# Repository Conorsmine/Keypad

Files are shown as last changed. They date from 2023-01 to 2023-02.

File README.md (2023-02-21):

# Keypad
Current progress on the project:


## Resources
ai03 Guide:       https://wiki.ai03.com/books/pcb-design/page/pcb-guide-part-5---creating-the-pcb  
Masterzen Guide:  https://www.masterzen.fr/2020/10/20/designing-a-keyboard-part3/

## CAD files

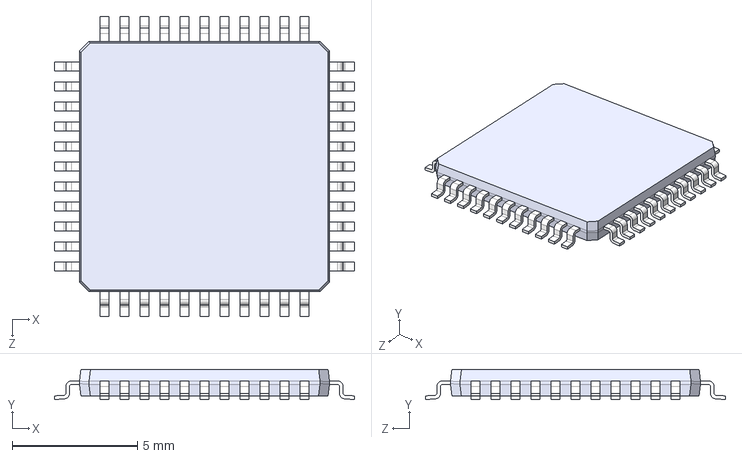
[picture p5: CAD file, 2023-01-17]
keypad/ATMEGA32U4-AU/ATMEGA32U4-AU.step
12.0 x 1.20 x 12.0 mm

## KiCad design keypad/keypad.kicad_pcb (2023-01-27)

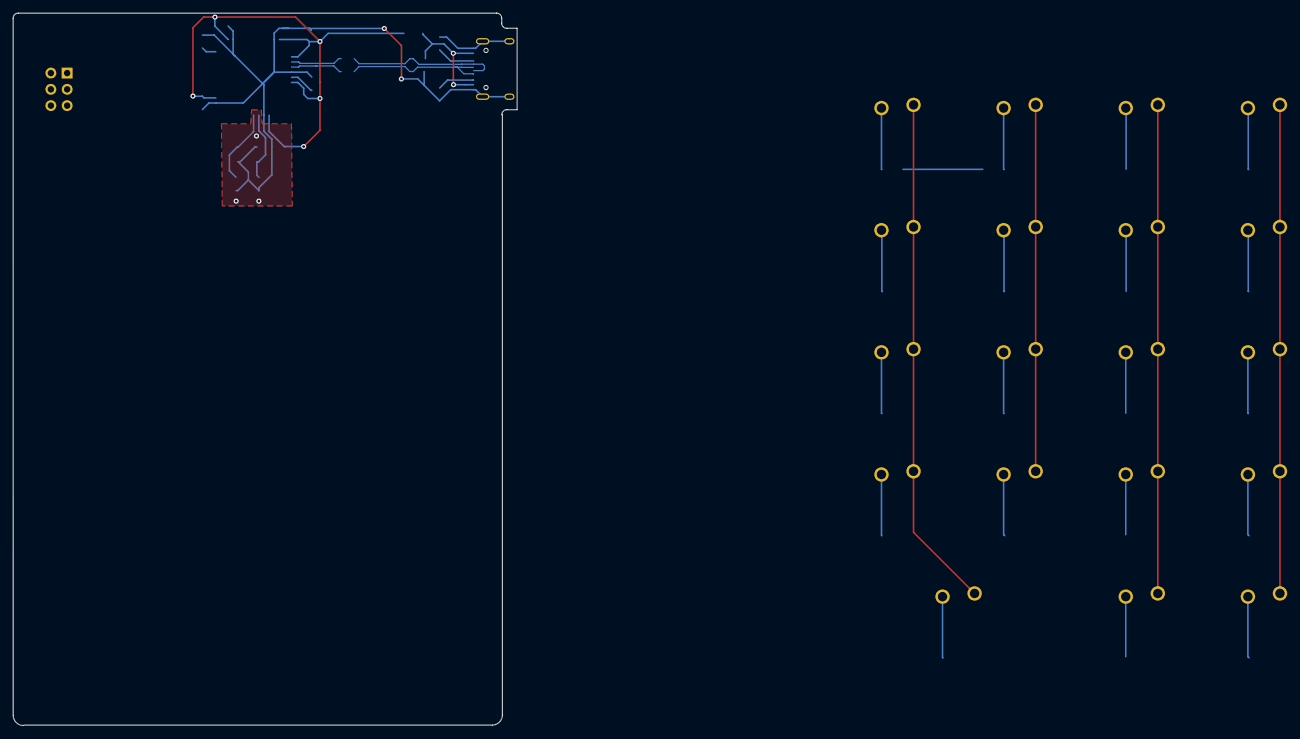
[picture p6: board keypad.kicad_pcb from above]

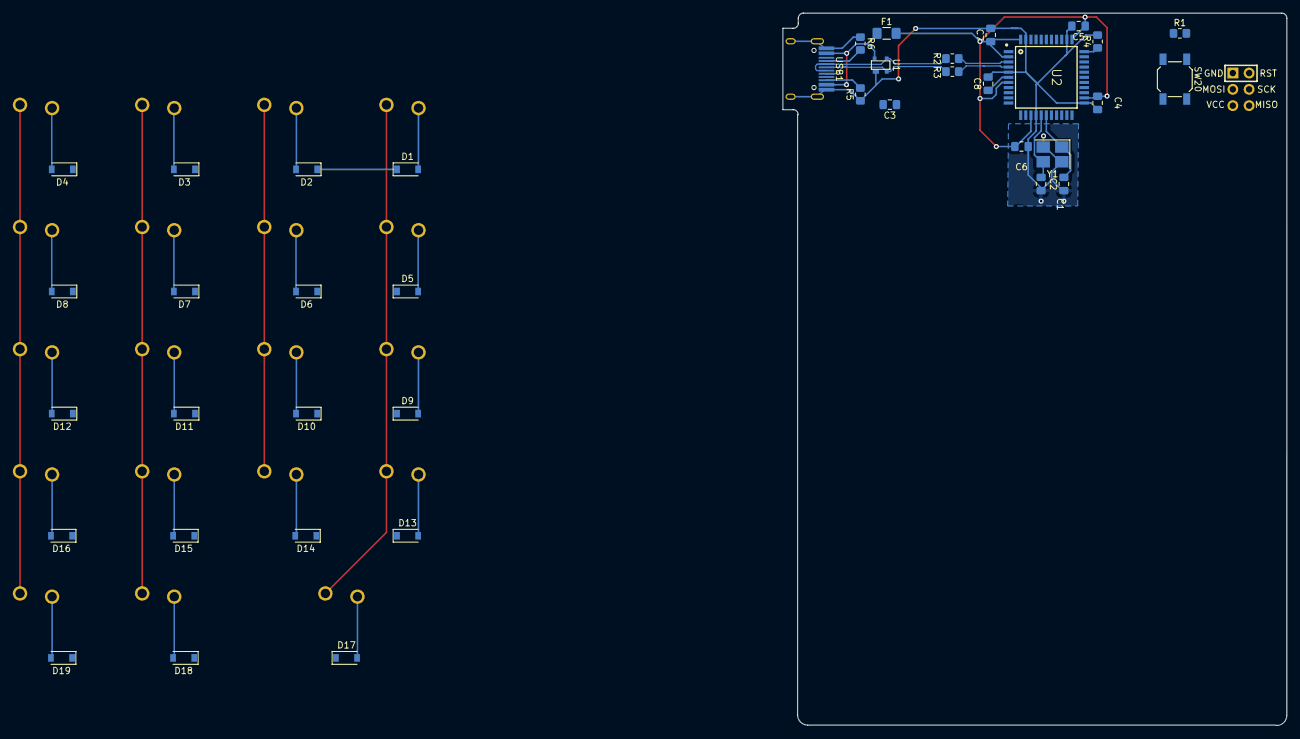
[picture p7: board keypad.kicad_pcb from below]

Board: 2 copper layers, 78.6 x 111.1 mm, 59 parts (40 on the bottom side), 45 nets.

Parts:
C1, C2: 22p; C_0805_2012Metric_Pad1.18x1.45mm_HandSolder
C3, C4, C5, C6: 0.1u; C_0805_2012Metric_Pad1.18x1.45mm_HandSolder
C7: 10u; C_0805_2012Metric_Pad1.18x1.45mm_HandSolder
C8: 1u; C_0805_2012Metric_Pad1.18x1.45mm_HandSolder
D1, D2, D3, D4, D5, D6, D7, D8, D9, D10, D11, D12, D13, D14, D15, D16, D17, D18, D19: D; D_SOD-123
F1: 500mA; Fuse_1206_3216Metric_Pad1.42x1.75mm_HandSolder
J1: AVR-ISP-6; Reset_Pretty-Mask
R1, R4: 10k; R_0805_2012Metric_Pad1.20x1.40mm_HandSolder
R2, R3: 22; R_0805_2012Metric_Pad1.20x1.40mm_HandSolder
R5, R6: 5.1k; R_0805_2012Metric_Pad1.20x1.40mm_HandSolder
SW1: num; ALPS-1U
SW2: div; ALPS-1U
SW3: mult; ALPS-1U
SW4: min; ALPS-1U
SW5: #7; ALPS-1U
SW6: #8; ALPS-1U
SW7: #9; ALPS-1U
SW8: plu0; ALPS-1U
SW9: #4; ALPS-1U
SW10: #5; ALPS-1U
SW11: #6; ALPS-1U
SW12: plu1; ALPS-1U
SW13: #1; ALPS-1U
SW14: #2; ALPS-1U
SW15: #3; ALPS-1U
SW16: ent0; ALPS-1U
SW17: #0; ALPS-2U
SW18: kom; ALPS-1U
SW19: ent1; ALPS-1U
SW20: SW_Push_Reset; SW_SPST_SKQG_WithStem
U1: PRTR5V0U2X; SOT143B
U2: ATMEGA32U4-AU; QFP80P1200X1200X120-44N
USB1: HRO-TYPE-C-31-M-12; HRO-TYPE-C-31-M-12-HandSoldering
Y1: XTAL; Crystal_SMD_3225-4Pin_3.2x2.5mm_HandSoldering

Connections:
+5V: C3.1, C4.1, C5.1, C6.1, C7.1, F1.2, J1.2 (VCC), R1.1, U2.2 (UVCC), U2.7 (VBUS), U2.14 (VCC), U2.24 (AVCC), U2.34 (VCC), U2.44 (AVCC)
/D+: R3.2, U2.4 (D+)
/D-: R2.2, U2.3 (D-)
/MISO: J1.1 (MISO), U2.11 (PB3)
/MOSI: J1.4 (MOSI), U2.10 (PB2)
/Reset: J1.5 (~RST), R1.2, SW20.1 (Pass), U2.13 (~RESET)
/SCK: J1.3 (SCK), U2.9 (PB1)
/XTAL1: C1.1, U2.17 (XTAL1), Y1.1
/XTAL2: C2.1, U2.16 (XTAL2), Y1.3
DN: R2.1, U1.3 (IO2), USB1.5 (DN2), USB1.7 (DN1)
DP: R3.1, U1.2 (IO1), USB1.6 (DP1), USB1.8 (DP2)
GND: C1.2, C2.2, C3.2, C4.2, C5.2, C6.2, C7.2, C8.2, J1.6 (GND), R4.2, R5.1, R6.1, SW20.2 (ve), U1.1 (GND), U2.5 (UGND), U2.15 (GND), U2.23 (GND), U2.35 (GND), U2.43 (GND), USB1.1 (GND), USB1.12 (GND), USB1.13 (SHIELD), Y1.2, Y1.4
unnamed: C8.1, U2.6 (UCAP)
unnamed: D1.2 (A), SW1.1
unnamed: D2.2 (A), SW2.1
unnamed: D3.2 (A), SW3.1
unnamed: D4.2 (A), SW4.1
unnamed: D5.2 (A), SW5.1
unnamed: D6.2 (A), SW6.1
unnamed: D7.2 (A), SW7.1
unnamed: D8.2 (A), SW8.1
unnamed: D9.2 (A), SW9.1
unnamed: D10.2 (A), SW10.1
unnamed: D11.2 (A), SW11.1
unnamed: D12.2 (A), SW12.1
unnamed: D13.2 (A), SW13.1
unnamed: D14.2 (A), SW14.1
unnamed: D15.2 (A), SW15.1
unnamed: D16.2 (A), SW16.1
unnamed: D17.2 (A), SW17.1
unnamed: D18.2 (A), SW18.1
unnamed: D19.2 (A), SW19.1
unnamed: R4.1, U2.33 (PE2)
unnamed: R5.2, USB1.10 (CC2)
unnamed: R6.2, USB1.4 (CC1)
VCC: F1.1, U1.4 (VCC), USB1.2 (VBUS), USB1.11 (VBUS)
col0: SW1.2, SW5.2, SW9.2, SW13.2, SW17.2, U2.32 (PC7)
col1: SW2.2, SW6.2, SW10.2, SW14.2, U2.31 (PC6)
col2: SW3.2, SW7.2, SW11.2, SW15.2, SW18.2, U2.29 (PB5)
col3: SW4.2, SW8.2, SW12.2, SW16.2, SW19.2, U2.30 (PB6)
row0: D1.1 (K), D2.1 (K), D3.1 (K), D4.1 (K), U2.22 (PD5)
row1: D5.1 (K), D6.1 (K), D7.1 (K), D8.1 (K), U2.21 (PD3)
row2: D9.1 (K), D10.1 (K), D11.1 (K), D12.1 (K), U2.20 (PD2)
row3: D13.1 (K), D14.1 (K), D15.1 (K), D16.1 (K), U2.19 (PD1)
row4: D17.1 (K), D18.1 (K), D19.1 (K), U2.18 (PD0)

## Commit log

2023-01-17 Add Footprint Libraries
2023-01-17 Add symbol and footprints
2023-01-17 Add ATMEGA32U4-AU librarie
    [ATMEGA32U4-AU.step, keypad.kicad_sch]
2023-01-17 Scheme 1.0 complete
    [keypad.kicad_sch]
2023-01-17 Creat Matrix 1.0
    [keypad.kicad_sch, matrix.kicad_sch]
2023-01-17 Assign Footprints
    [keypad.kicad_sch, matrix.kicad_sch]
2023-01-17 PCB Layout
    [keypad.kicad_pcb]
2023-01-17 Add Main layout
    Note that some of the layering is probably wrong. Check that again.
    [keypad.kicad_pcb]
2023-01-18 Fixed Layering
    Also as a note, there was a rogue 1uF capacitor which I now just placed under the usb, out of the way. It may be needed later.
    [keypad.kicad_pcb, keypad.kicad_sch]
2023-01-18 Started Routing
    [keypad.kicad_pcb, keypad.kicad_sch]
2023-01-18 Removed Routing and Replaced components
    [keypad.kicad_pcb]
2023-01-19 Routed D-Pair and Matrix
    [keypad.kicad_pcb]
2023-01-27 Routed crystal oscillator
    [keypad.kicad_pcb]
2023-01-27 Added ground plane
    [keypad.kicad_pcb]
2023-01-27 Routed USB VCC
    [keypad.kicad_pcb]
2023-01-27 Added 5V and GND routes to MCU
2023-01-27 Connected 5V/GND to USB
    [keypad.kicad_pcb]
